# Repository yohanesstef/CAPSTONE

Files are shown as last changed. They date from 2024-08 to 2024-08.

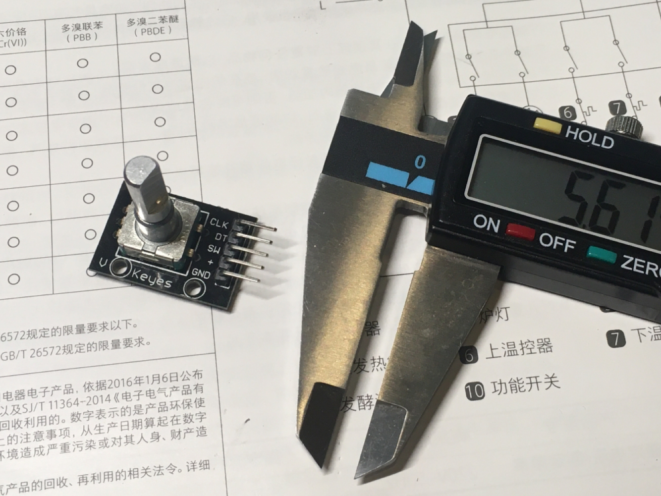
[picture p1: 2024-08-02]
full-bridge-inverter/ky-040-rotary-encoder-1.snapshot.1/Rotary Encoder - ODG/image/Measured by hand.png

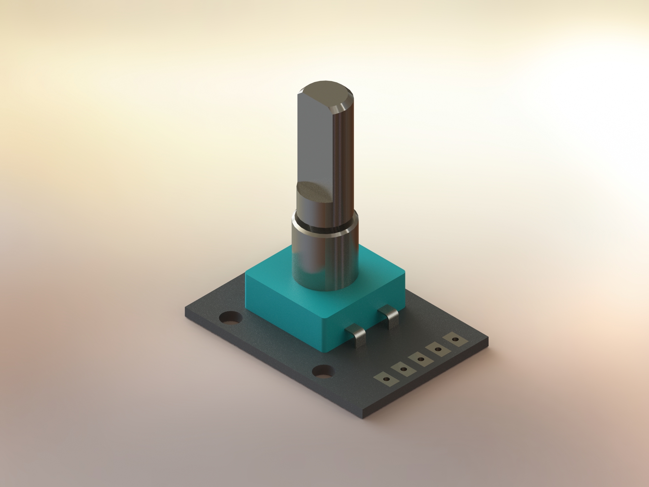
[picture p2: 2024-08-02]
full-bridge-inverter/rotary-encoder-ky-040-1.snapshot.3/Render Encoder 1.JPG

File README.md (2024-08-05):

# Wireless Power Transfer - CAPSTONE Project
WhatsApp Image 2024-08-05 at 20 47 46_10204884
This is repository for a Wireless Power Transfer. I have completed this project in semester 6 as an assignment for the CAPSTONE course. In this repository there are three PCB board that I design using KiCad 7.0. The boards are 12V Fullbridge Inverter, transmitter-board, and receiver-board. 
## Important notes !!!
This repository file management maybe kinda messy. But you can find 12V Fullbridge inside the directory:
```bash
.\full-bridge-inverter\full-bridge-inverter
```
That directory also includes Proteus simulation and source code for Arduino Nano.

Transmitter-board inside the directory:
```bash
.\transmitter-board
```
and receiver-board inside the directory:
```bash
.\receiver-board
```
## 1. 12V Fullbridge Inverter
This full-bridge inverter can convert 12VDC to 12VAC with a frequency ranging from 80kHz to 200kHz. This inverter is controlled by an Arduino Nano as the PWM generator. On the bottom left side of the board, you can adjust the frequency, and the value will be shown on the 0.91-inch OLED display.
### Simulation
Below is the simulation at maximum frequency (200kHz):


Below is the simulation at minimum frequency (80kHz):


### Schematic
Preview

### Layout


### Board Image

WhatsApp Image 2024-08-05 at 19 57 58_32873d33

### Specification
| Input Voltage | Output Voltage | Max Output Current | Operating Frequency |
| :---: | :---: | :---: | :---: |
| 5VDC - 15VDC | 7VAC - 15VAC | 3A | 80kHz - 200kHz* |

*operating frequency can be changed by program up to 1MHz
## 2. Transmitter Board
This transmitter board uses an LC series connection. This configuration helps reduce its impedance so the current flow can be maximized. The capacitor can be added or replaced with another one since the board uses an XT30 connector for the capacitor. The capacitor value needs to be calculated based on the resonant frequency to achieve maximum power transfer.



### Schematic


### Layout


### Board Image

WhatsApp Image 2024-08-05 at 19 57 39_28c1e7be
WhatsApp Image 2024-08-05 at 19 57 39_5e4d0d41

## 3. Receiver Board
This receiver board is similar to the transmitter board. The difference is that the receiver board uses an LC parallel connection to minimize its impedance and behave like a purely resistive circuit.
### Schematic


### Layout


### Board Image

WhatsApp Image 2024-08-05 at 20 37 52_3ca948d0
WhatsApp Image 2024-08-05 at 19 57 38_17e0c154

Do contact me if you have some question or want to colaborate with me.

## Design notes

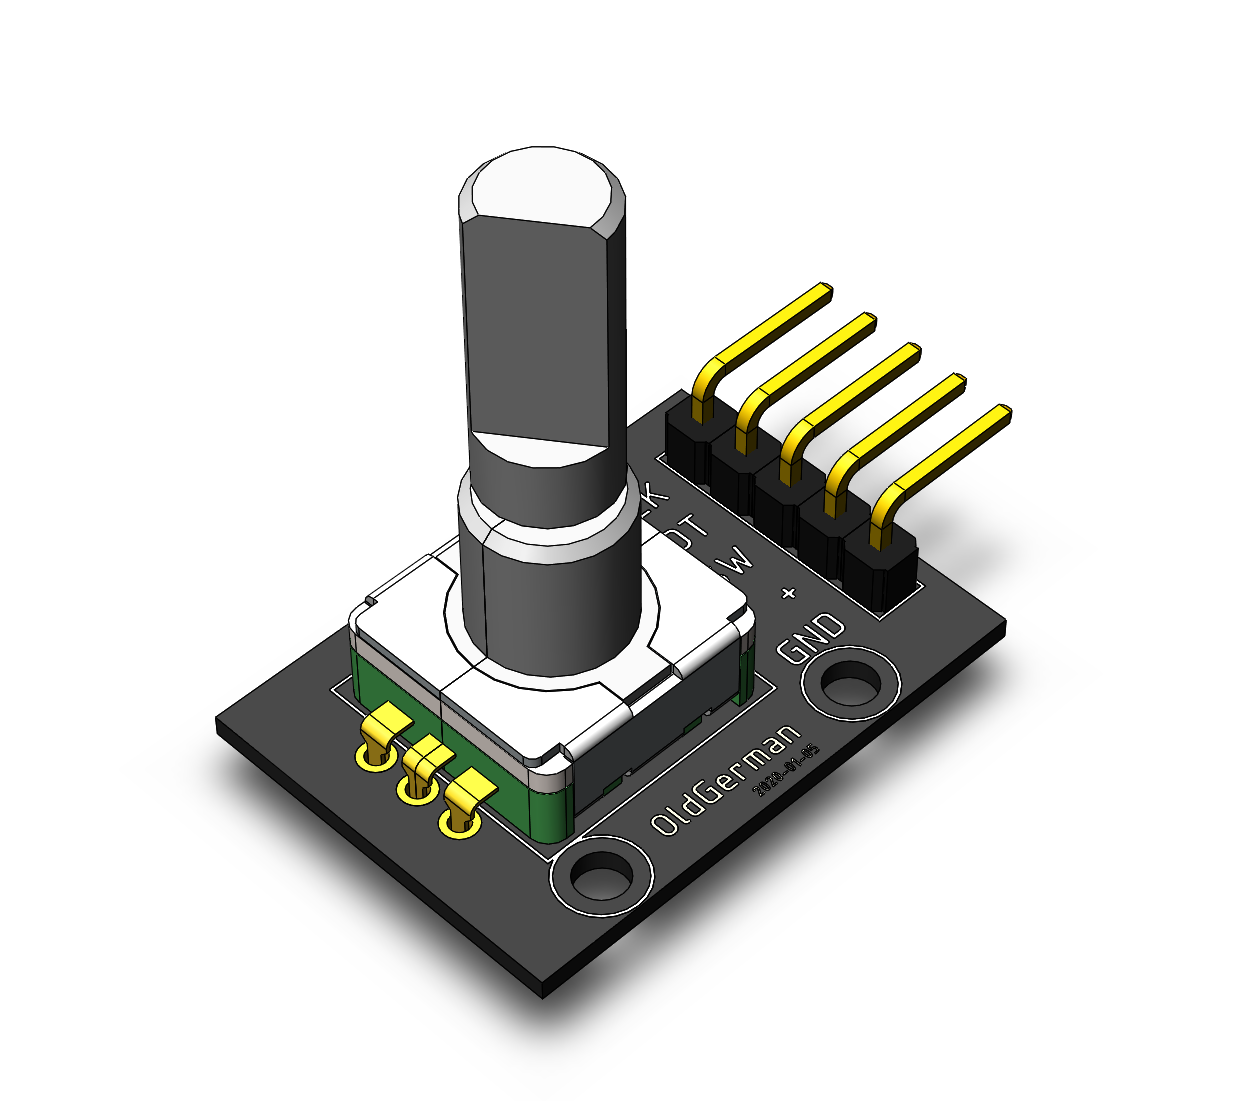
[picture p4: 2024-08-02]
full-bridge-inverter/ky-040-rotary-encoder-1.snapshot.1/Rotary Encoder - ODG/image/perspective 1 .png

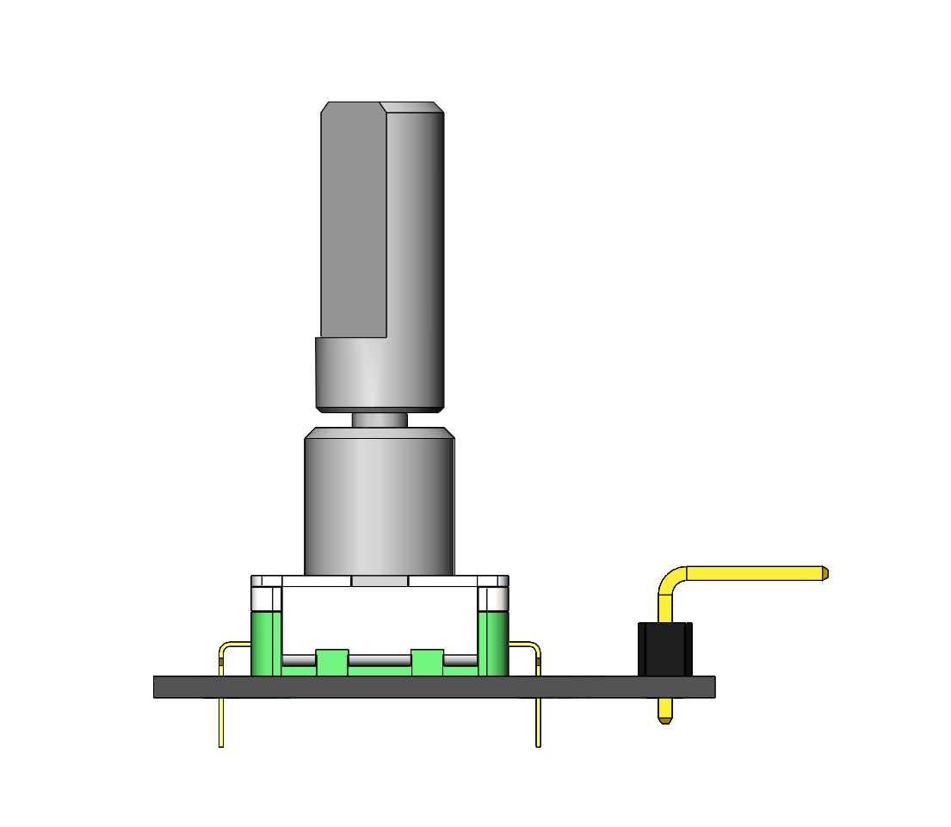
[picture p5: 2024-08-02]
full-bridge-inverter/ky-040-rotary-encoder-1.snapshot.1/Rotary Encoder - ODG/image/left.png

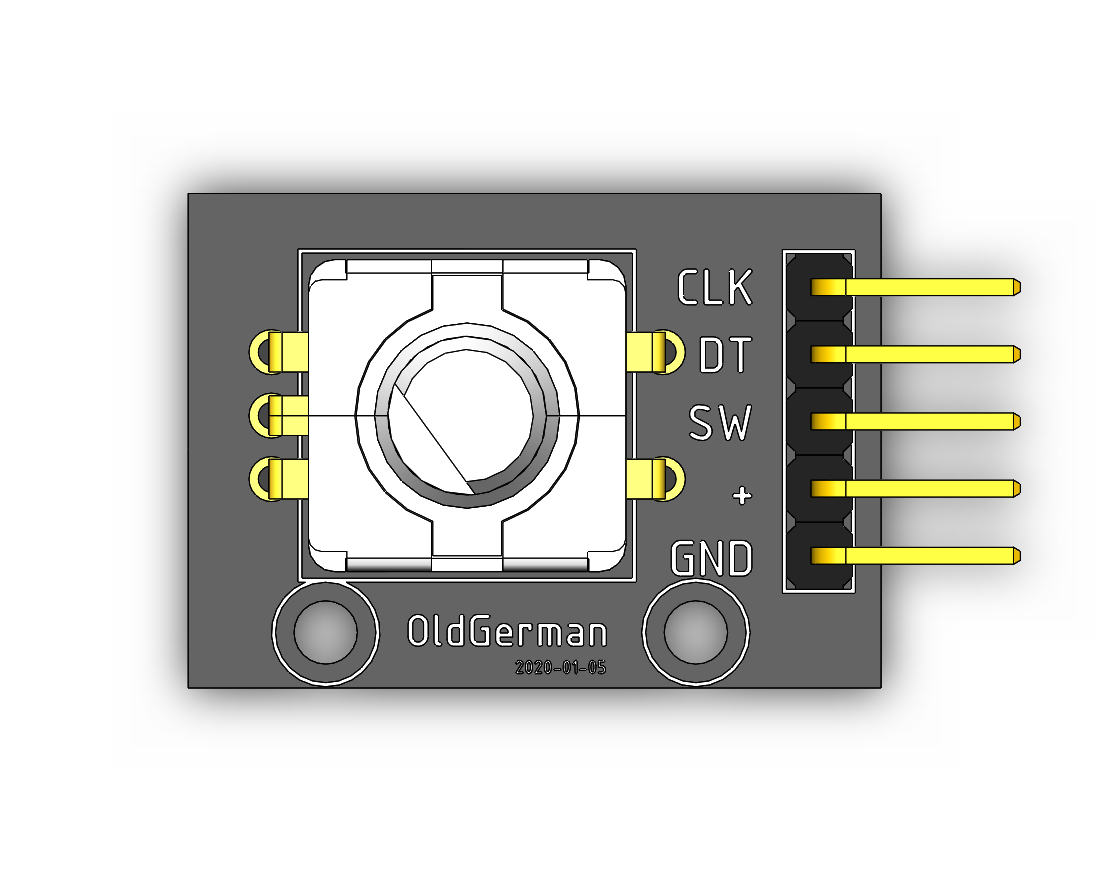
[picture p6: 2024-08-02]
full-bridge-inverter/ky-040-rotary-encoder-1.snapshot.1/Rotary Encoder - ODG/image/top.png

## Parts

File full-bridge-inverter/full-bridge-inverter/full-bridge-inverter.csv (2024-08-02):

Source: | C:\Users\ystef\Documents\KiCad\Project\CAPSTONE\full-bridge-inverter\full-bridge-inverter\full-bridge-inverter.kicad_sch
Date: | 18/06/2024 14:32:58
Tool: | Eeschema 7.0.10
Generator: | C:\Program Files\KiCad\7.0\bin\scripting\plugins/bom_csv_grouped_by_value_with_fp.py
Component Count: | 38
Ref | Qnty | Value | Cmp name | Footprint | Description | Vendor | DNP
A1 | 1 | Arduino_Nano_v3.x | Arduino_Nano_v3.x | Module:Arduino_Nano | Arduino Nano v3.x
C1, C7, C10 | 3 | 100u | C | Capacitor_THT:C_Radial_D8.0mm_H11.5mm_P3.50mm | Unpolarized capacitor
C2, C4, C5, C6, C11 | 5 | 10u | C | Capacitor_THT:C_Radial_D5.0mm_H11.0mm_P2.00mm | Unpolarized capacitor
C3 | 1 | 100n | C | Capacitor_THT:C_Disc_D4.3mm_W1.9mm_P5.00mm | Unpolarized capacitor
C8, C9 | 2 | 47n | C | Capacitor_THT:C_Disc_D4.3mm_W1.9mm_P5.00mm | Unpolarized capacitor
D1, D3 | 2 | 1N5820 | 1N5820 | Diode_THT:D_DO-201AD_P15.24mm_Horizontal | 20V 3A Schottky Barrier Rectifier Diode, DO-201AD
H1, H2, H3, H4 | 4 | MountingHole | MountingHole | MountingHole:MountingHole_3.2mm_M3_DIN965 | Mounting Hole without connection
J1, J2 | 2 | Screw_Terminal_01x02 | Screw_Terminal_01x02 | HB9500:HB9500 | Generic screw terminal, single row, 01x02, script generated (kicad-library-utils/schlib/autogen/connector/)
Q1, Q2, Q3, Q4 | 4 | IRLZ44N | IRLZ44N | Package_TO_SOT_THT:TO-220-3_Vertical | 47A Id, 55V Vds, 22mOhm Rds Single N-Channel HEXFET Power MOSFET, TO-220AB
R1, R2, R7, R8 | 4 | 10k | R | Resistor_THT:R_Axial_DIN0411_L9.9mm_D3.6mm_P12.70mm_Horizontal | Resistor
R3, R4, R5, R6 | 4 | 10 | R | Resistor_THT:R_Axial_DIN0411_L9.9mm_D3.6mm_P12.70mm_Horizontal | Resistor
U1 | 1 | LM7805_TO220 | LM7805_TO220 | Package_TO_SOT_THT:TO-220-3_Vertical | Positive 1A 35V Linear Regulator, Fixed Output 5V, TO-220
U2 | 1 | KY-040 | KY-040 | KY-040:KY-040-PORT
U3 | 1 | OLED-0.91 | OLED-0.91 | KiCad-SSD1306-0.91-OLED-4pin-128x32.pretty-master:SSD1306-0.91-OLED-4pin-128x32
U4, U5 | 2 | IR2110 | IR2110 | Package_DIP:DIP-14_W7.62mm_Socket_LongPads | High and Low Side Driver, 500V, 2.0/2.0A, PDIP-14
U6 | 1 | 74LS04 | 74LS04 | Package_DIP:DIP-14_W7.62mm_Socket_LongPads | Hex Inverter

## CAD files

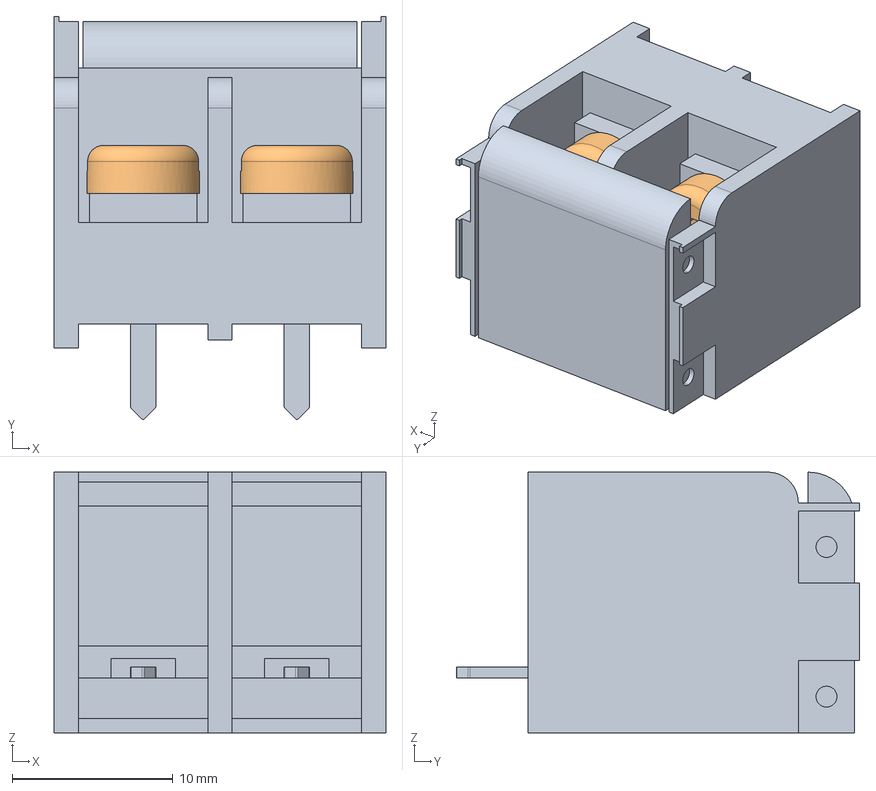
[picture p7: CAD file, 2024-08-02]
full-bridge-inverter/hb9500-barrier-teminal-block-1.snapshot.2/hb9500_asm.stp
20.6 x 25.0 x 16.2 mm
HB9500-1
M5X6 x 2

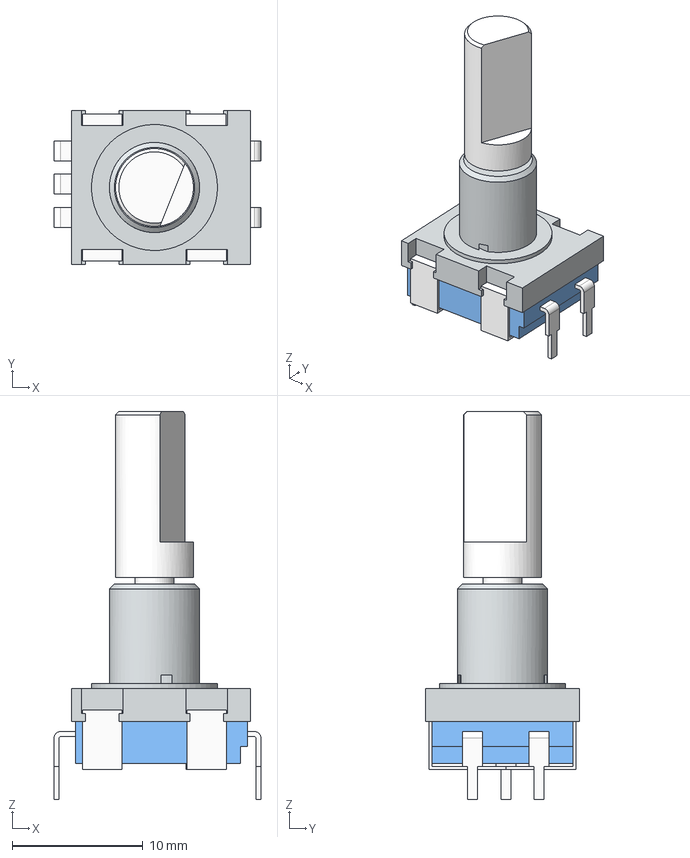
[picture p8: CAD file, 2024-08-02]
full-bridge-inverter/rotary encoder step files/Step Files/Rotary Encoder without pcb Assembly.stp
15.8 x 11.8 x 29.7 mm
mtg flange
body_encoder
pins_encoder body_2 x 5
shaft_encoder

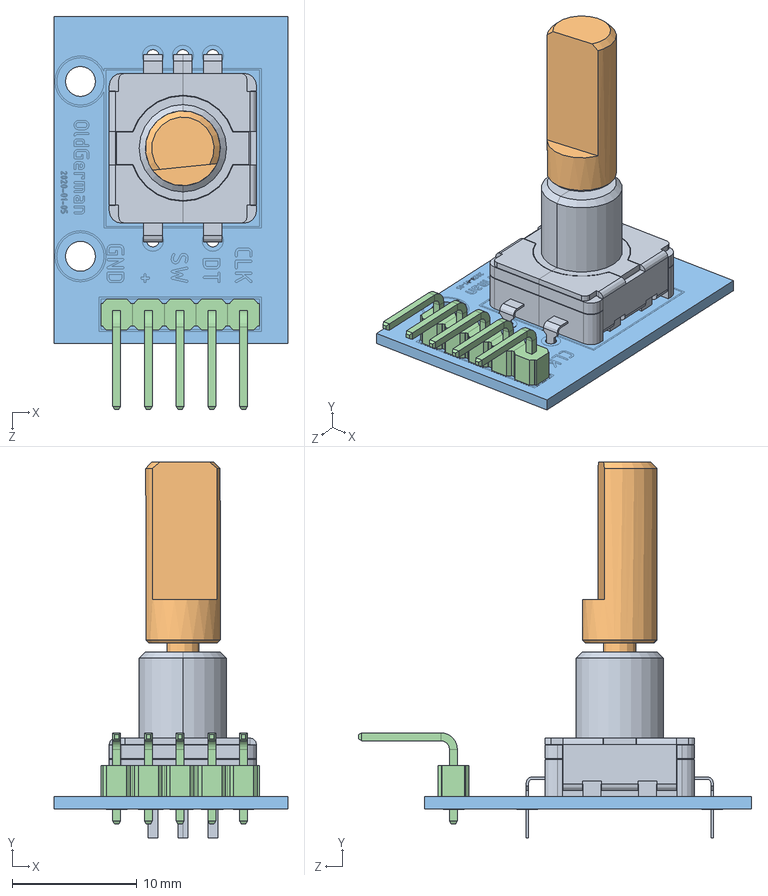
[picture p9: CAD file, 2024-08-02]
full-bridge-inverter/ky-040-rotary-encoder-1.snapshot.1/Rotary Encoder - ODG/sw2017 model/KY-040 Rotary Encoder.SLDASM
18.7 x 30.1 x 31.5 mm
Rotary Encoder
D-handle
pcb
2.54 5PIN 90

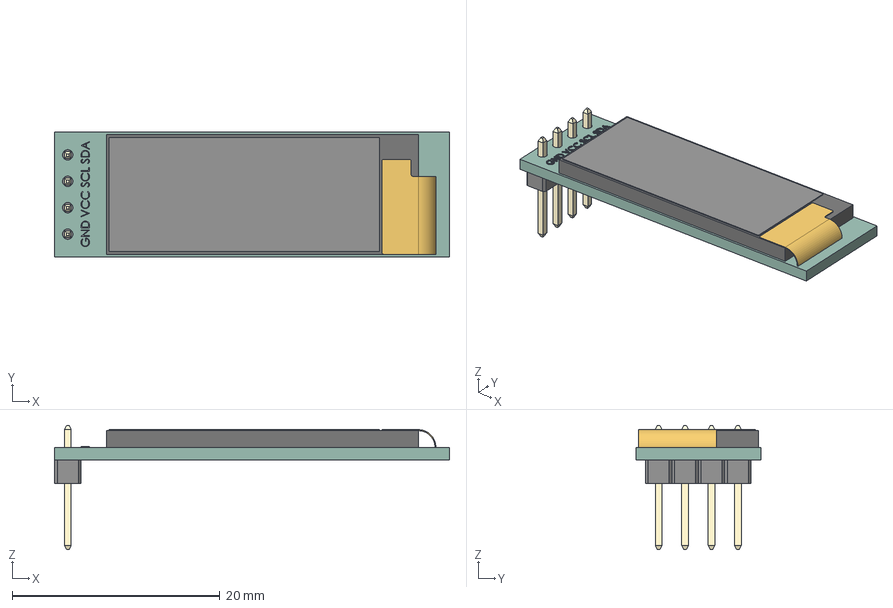
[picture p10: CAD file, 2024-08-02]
full-bridge-inverter/0-91-128x32-oled-display-1.snapshot.1/128x32-OLED.STEP
38.0 x 12.0 x 11.9 mm

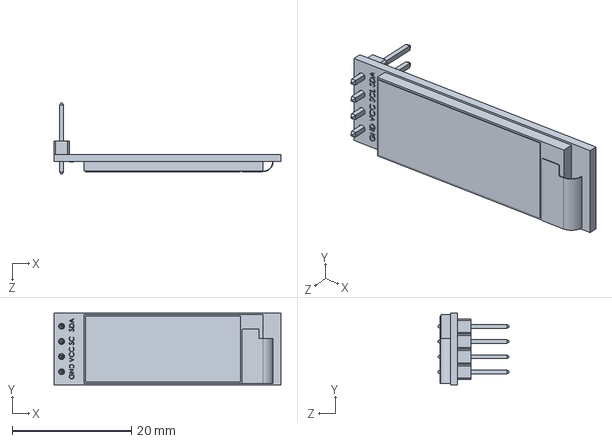
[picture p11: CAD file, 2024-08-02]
full-bridge-inverter/display-oled128x32-1.snapshot.4/128x32-OLED.STEP
38.0 x 12.0 x 11.9 mm

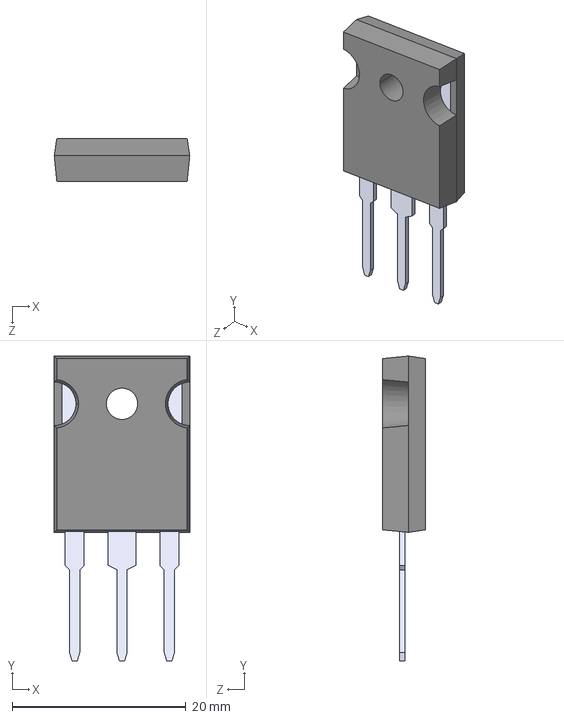
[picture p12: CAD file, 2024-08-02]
full-bridge-inverter/IRFP260N/IRFP260N.step
15.6 x 35.1 x 5.00 mm

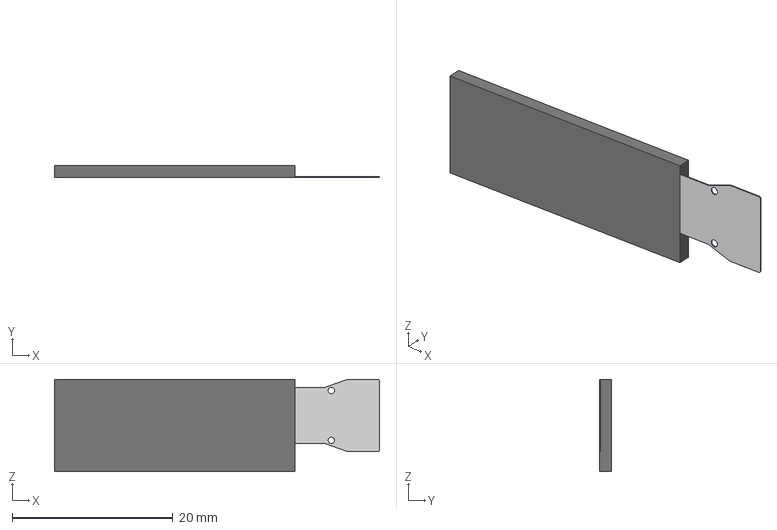
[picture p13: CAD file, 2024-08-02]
full-bridge-inverter/KiCad-SSD1306_OLED-0.91-128x32-master/SSD1306_OLED-0.91-128x32.step
40.5 x 1.45 x 11.5 mm

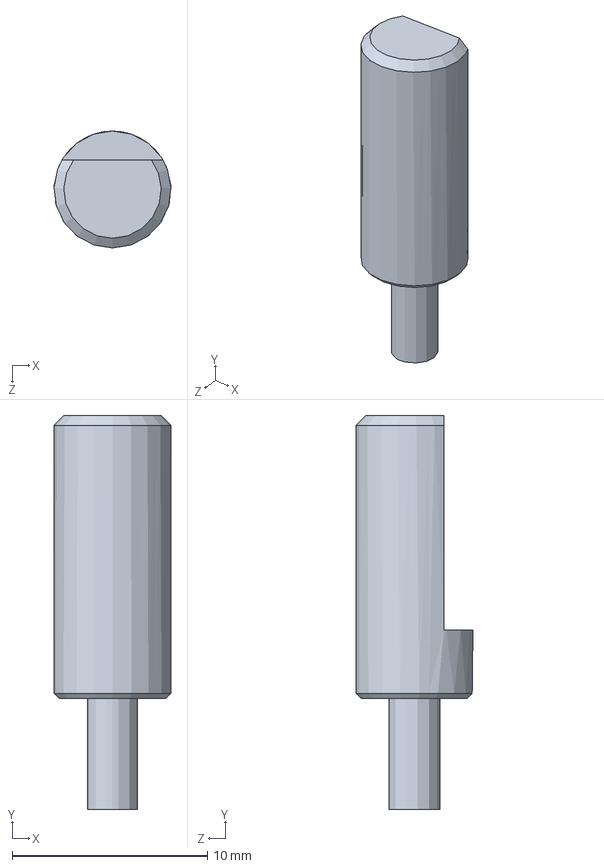
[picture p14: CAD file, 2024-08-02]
full-bridge-inverter/ky-040-rotary-encoder-1.snapshot.1/Rotary Encoder - ODG/sw2017 model/D-handle.SLDPRT
6.00 x 20.2 x 6.00 mm

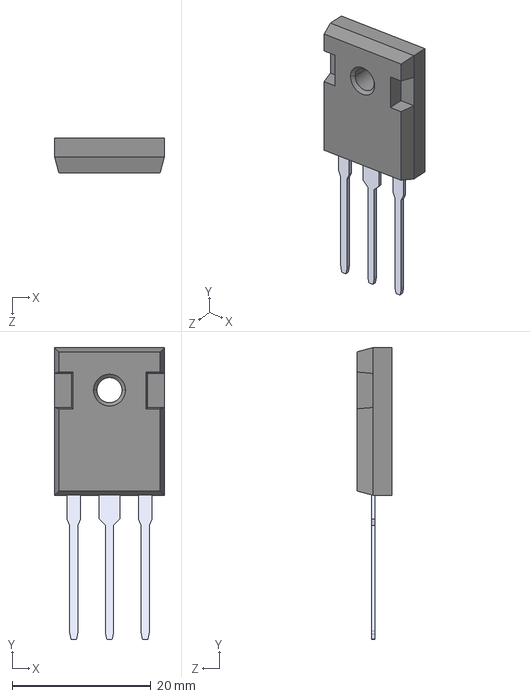
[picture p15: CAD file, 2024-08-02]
full-bridge-inverter/MUR3020WT/MUR3020WT.step
15.9 x 42.1 x 5.00 mm

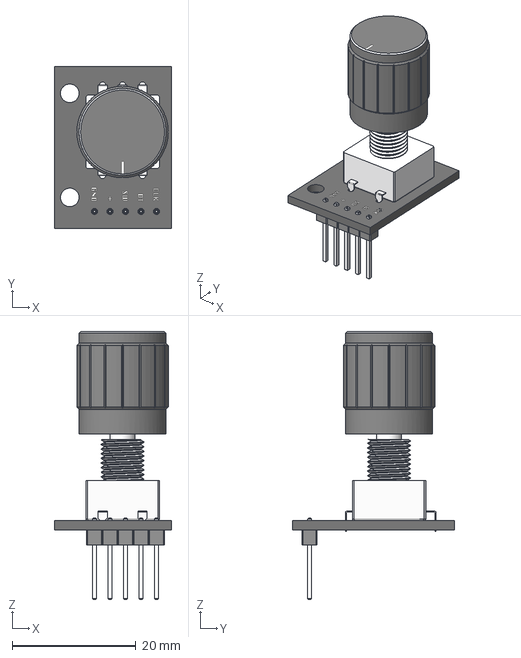
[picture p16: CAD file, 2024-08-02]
full-bridge-inverter/Rotary Encoder - KY-040.step
19.0 x 26.2 x 43.4 mm

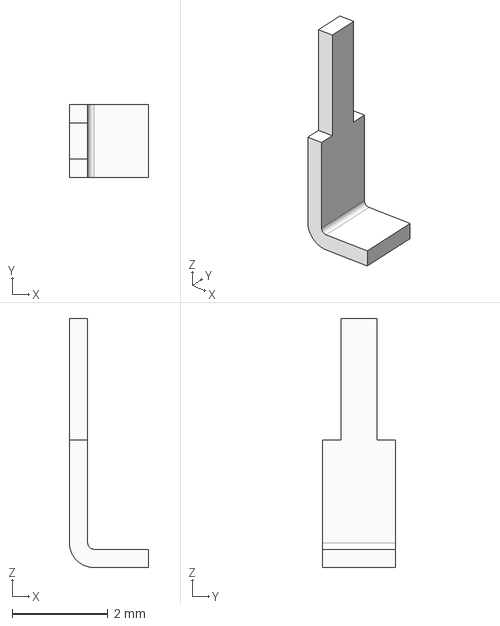
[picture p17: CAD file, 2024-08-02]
full-bridge-inverter/rotary encoder step files/Step Files/pins_encoder body_2.stp
1.65 x 1.52 x 5.21 mm

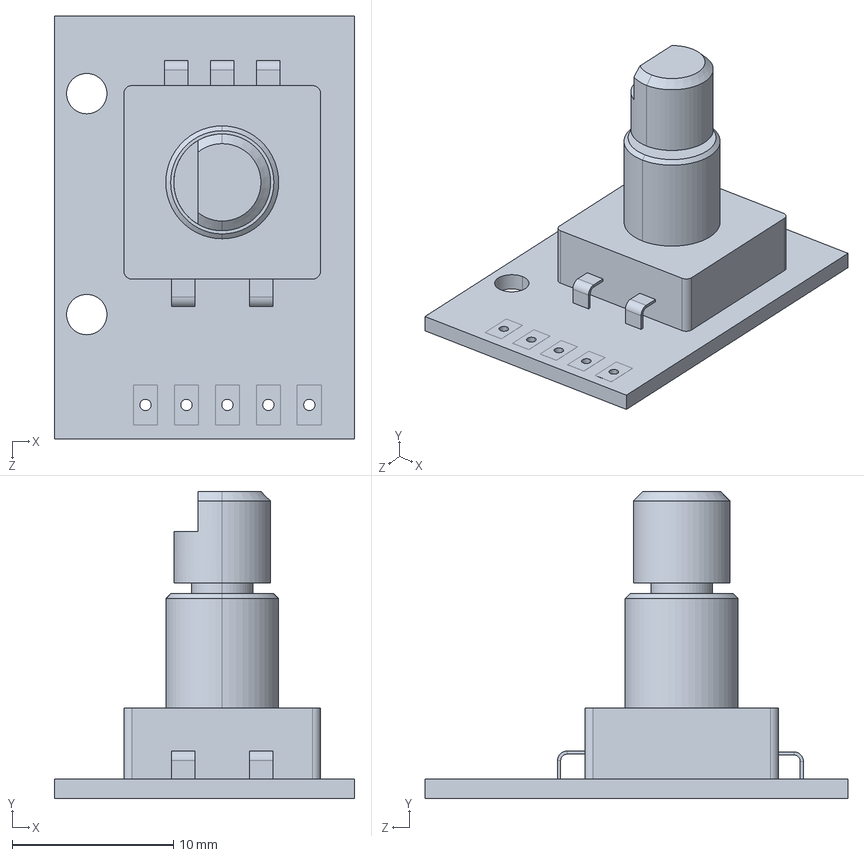
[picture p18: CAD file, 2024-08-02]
full-bridge-inverter/rotary-encoder-ky-040-1.snapshot.3/Encoder KY-040.STEP
18.6 x 19.1 x 26.2 mm

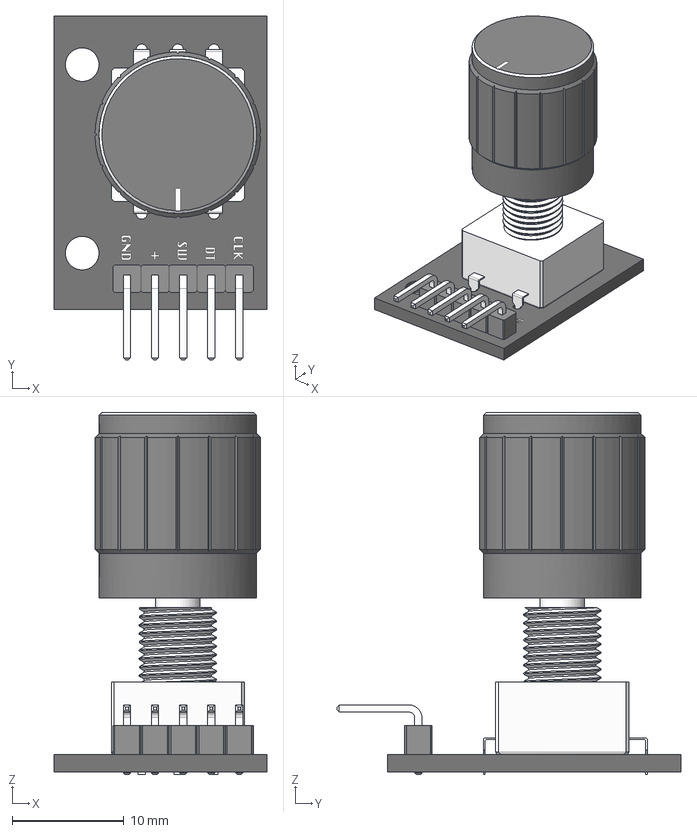
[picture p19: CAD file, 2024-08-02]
full-bridge-inverter/rotary-encoder-ky-040-2.snapshot.2/Rotary Encoder - KY-040.step
19.0 x 30.8 x 32.4 mm

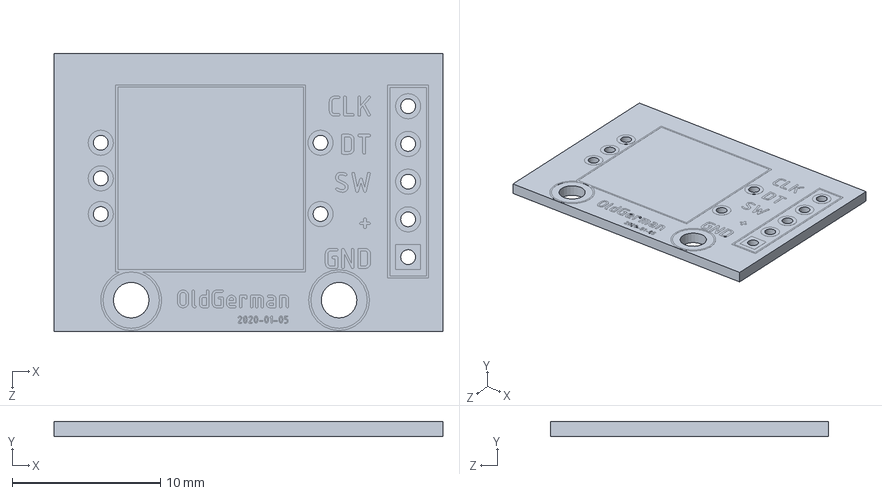
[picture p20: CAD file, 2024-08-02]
full-bridge-inverter/ky-040-rotary-encoder-1.snapshot.1/Rotary Encoder - ODG/sw2017 model/pcb.SLDPRT
26.2 x 1.02 x 18.7 mm

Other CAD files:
full-bridge-inverter/rotary encoder step files/Step Files/rotary encoder_chesr_2013.stp
full-bridge-inverter/ky-040-rotary-encoder-1.snapshot.1/Rotary Encoder - ODG/sw2017 model/Rotary Encoder.SLDPRT
full-bridge-inverter/rotary encoder step files/Step Files/90d pin_header.stp
full-bridge-inverter/ky-040-rotary-encoder-1.snapshot.1/Rotary Encoder - ODG/sw2017 model/2.54 5PIN 90.SLDPRT
full-bridge-inverter/Rotary Encoder/5 pin header.ipt
full-bridge-inverter/Rotary Encoder/90d pin_header.ipt
full-bridge-inverter/Rotary Encoder/OldVersions/mtg flange.0001.ipt
full-bridge-inverter/Rotary Encoder/OldVersions/pins_encoder body_2.0001.ipt
full-bridge-inverter/Rotary Encoder/OldVersions/pins_encoder body_2_2.0001.ipt
full-bridge-inverter/Rotary Encoder/OldVersions/rotary encoder_chesr_2013.0010.iam
full-bridge-inverter/Rotary Encoder/body_2.ipt
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

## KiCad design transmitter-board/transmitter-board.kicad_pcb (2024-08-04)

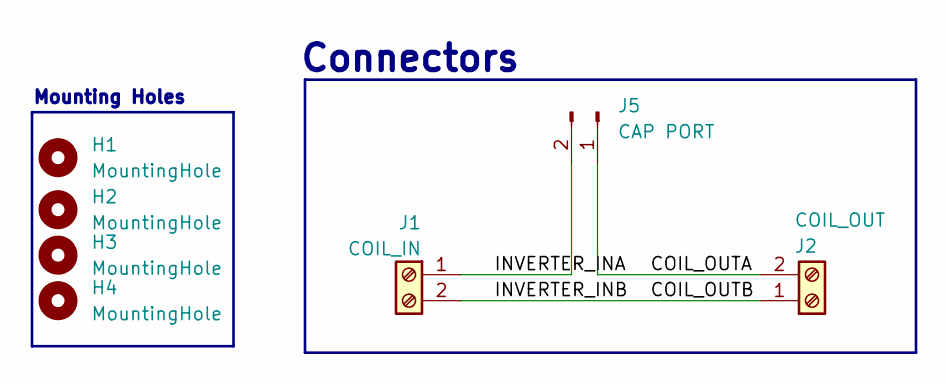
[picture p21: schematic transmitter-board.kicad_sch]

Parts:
H1, H2, H3, H4: MountingHole; MountingHole_3.2mm_M3
J1: COIL_IN; HB9500
J2: COIL_OUT; HB9500
J5: CAP PORT; AMASS_XT60-M_1x02_P7.20mm_Vertical

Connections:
/COIL_OUTA: J2.2, J5.1
/COIL_OUTB: J1.2, J2.1
/INVERTER_INA: J1.1, J5.2

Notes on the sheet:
Connectors
Mounting Holes

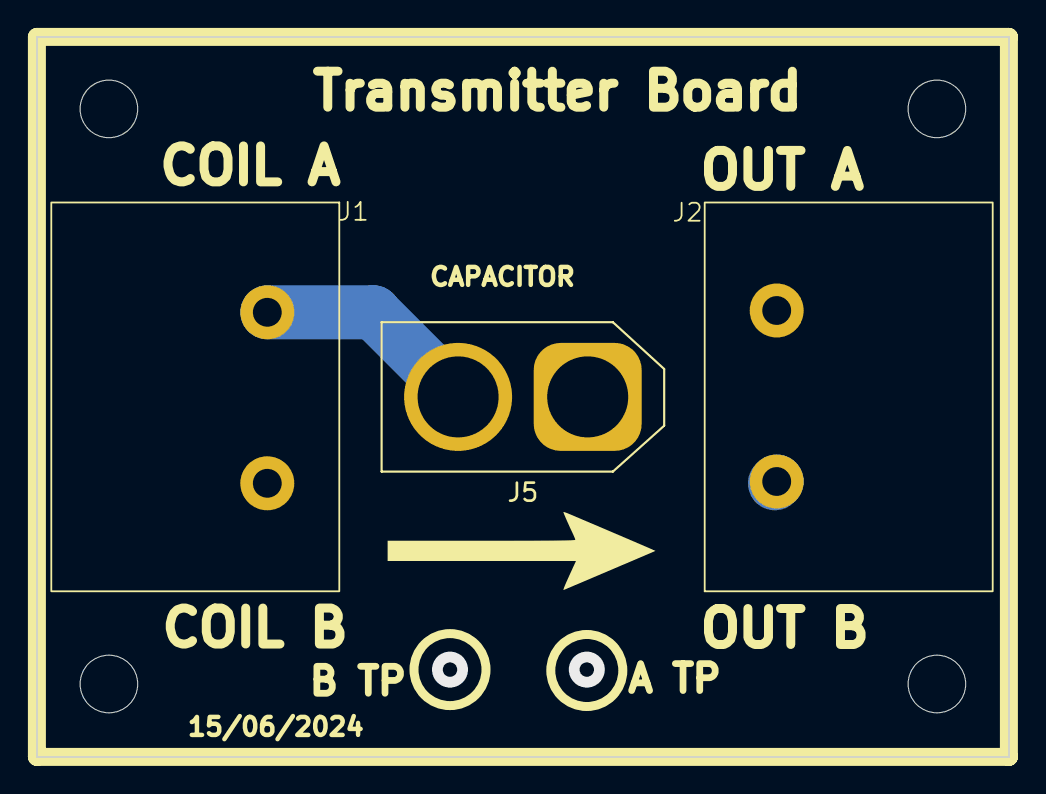
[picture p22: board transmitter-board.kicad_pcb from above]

Board: 2 copper layers, 54.0 x 40.0 mm, 7 parts (0 on the bottom side), 3 nets.

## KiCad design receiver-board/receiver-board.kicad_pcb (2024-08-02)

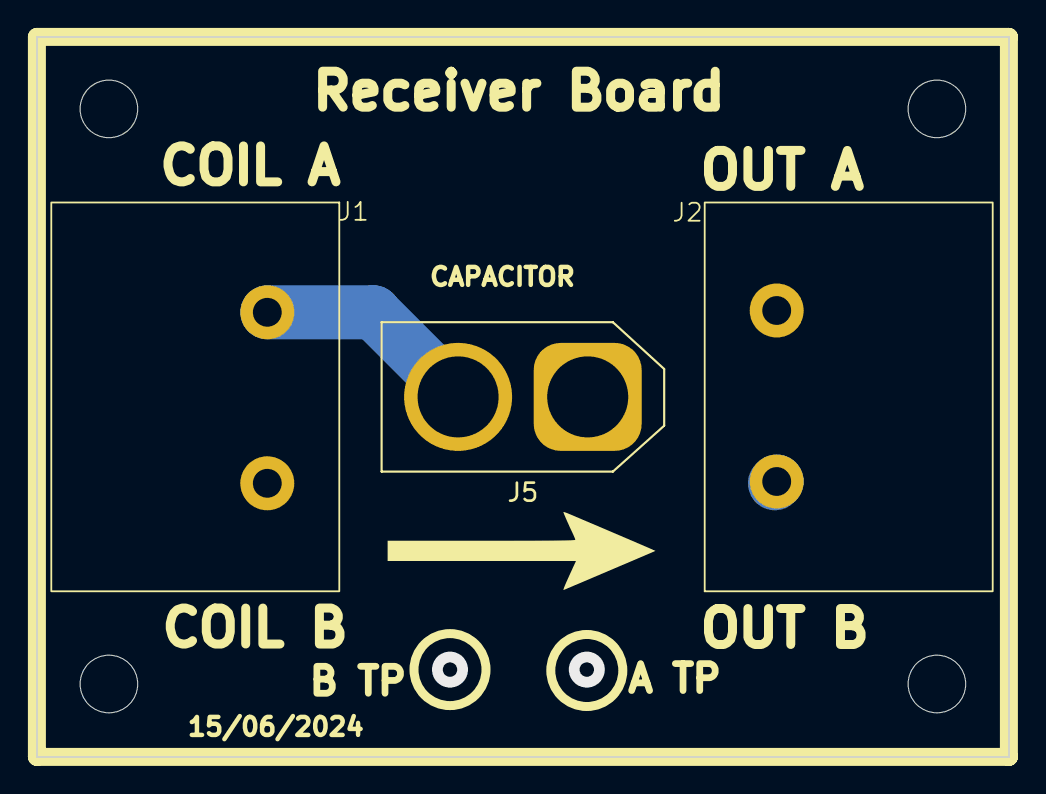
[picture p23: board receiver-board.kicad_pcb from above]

Board: 2 copper layers, 54.0 x 40.0 mm, 7 parts (0 on the bottom side), 2 nets.

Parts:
H1, H2, H3, H4: MountingHole; MountingHole_3.2mm_M3
J1, J2: Screw_Terminal_01x02; HB9500
J5: Conn_01x02_Pin; AMASS_XT60-M_1x02_P7.20mm_Vertical

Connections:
/COIL_OUTA: J1.1, J2.2, J5.2
/COIL_OUTB: J1.2, J2.1, J5.1

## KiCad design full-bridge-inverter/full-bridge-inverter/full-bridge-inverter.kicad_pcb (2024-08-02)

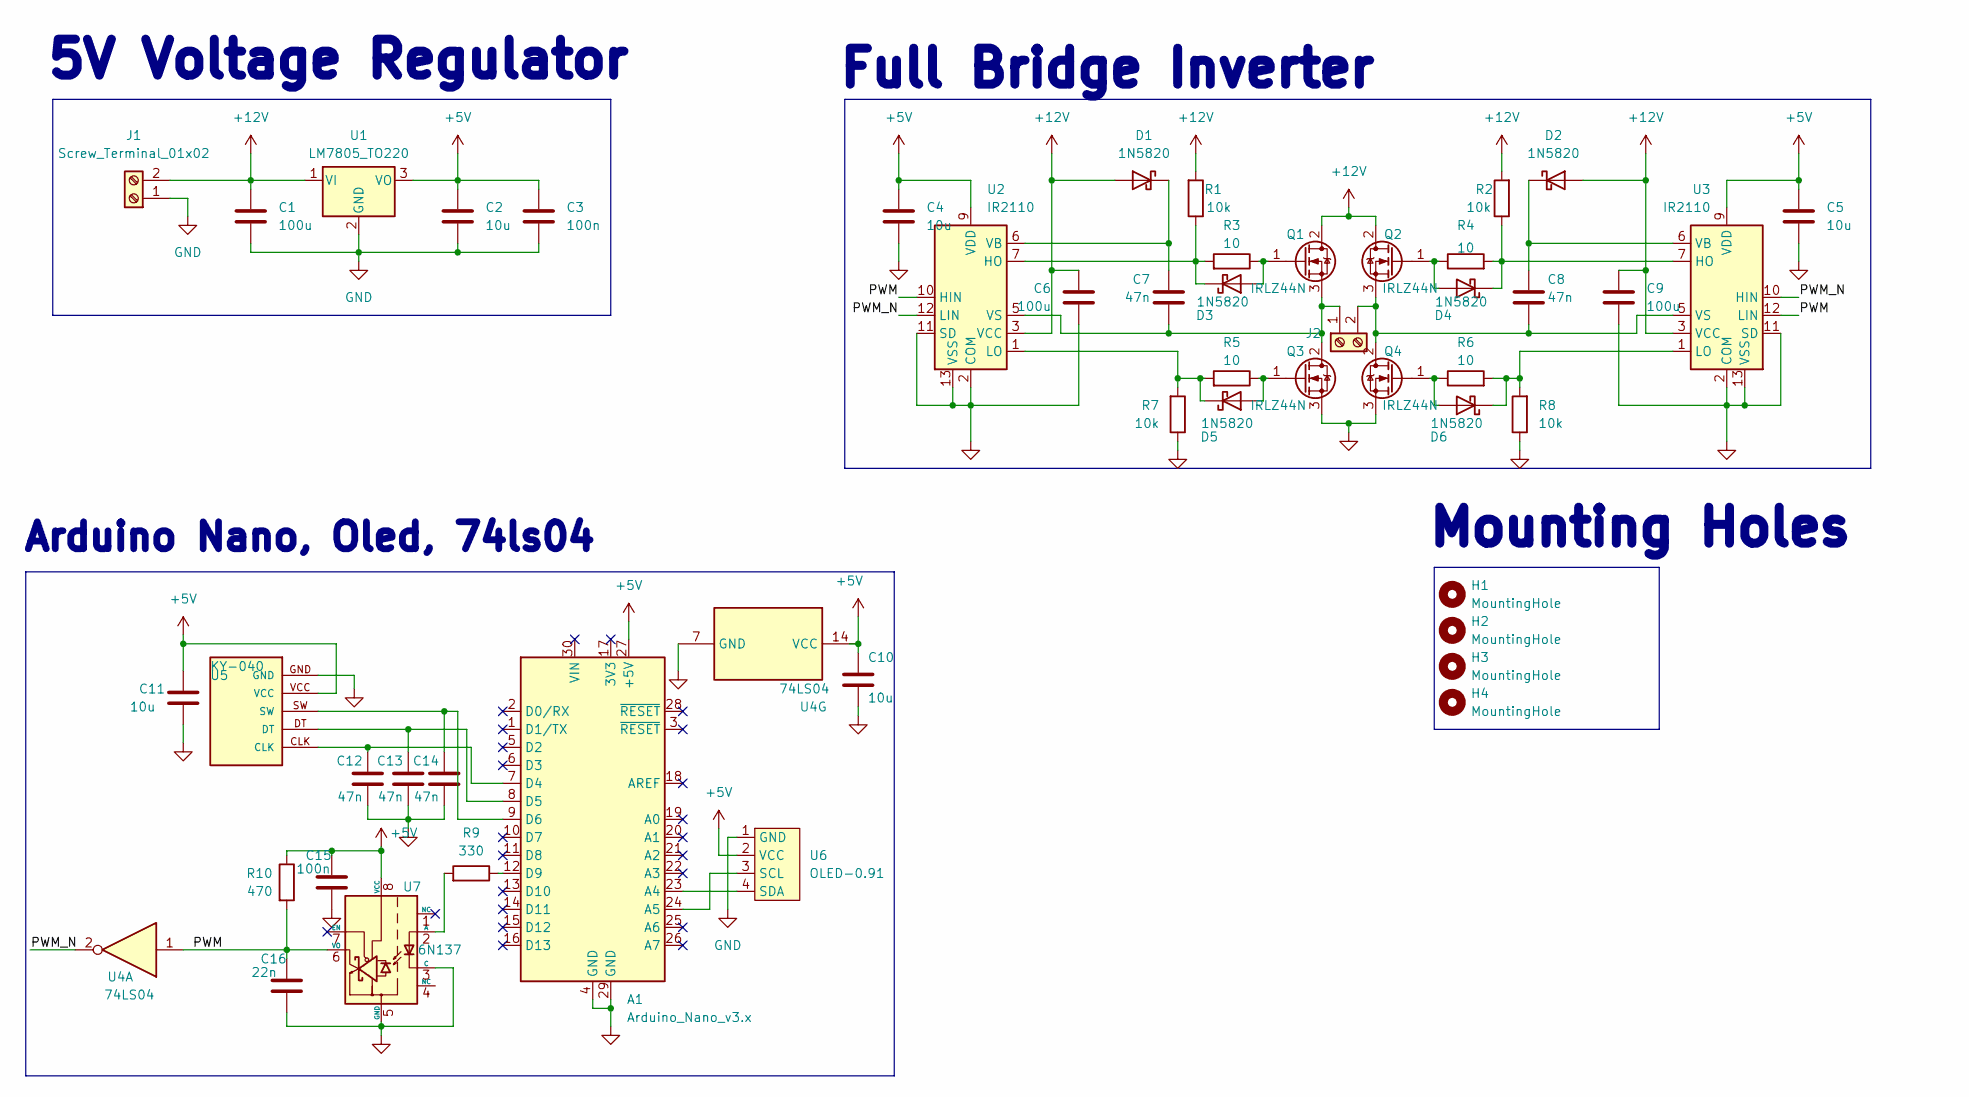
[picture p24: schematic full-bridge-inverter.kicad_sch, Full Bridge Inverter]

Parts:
A1: Arduino_Nano_v3.x; Arduino_Nano_v2
C1, C6, C9: 100u; C_Radial_D8.0mm_H11.5mm_P3.50mm
C2, C4, C5, C10, C11: 10u; C_Radial_D5.0mm_H11.0mm_P2.00mm
C3, C15: 100n; C_Disc_D4.3mm_W1.9mm_P5.00mm
C7, C8: 47n; C_Disc_D3.0mm_W1.6mm_P2.50mm
C12, C13, C14: 47n; C_Disc_D4.3mm_W1.9mm_P5.00mm
C16: 22n; C_Disc_D4.3mm_W1.9mm_P5.00mm
D1, D2, D3, D4, D5, D6: 1N5820; D_DO-201AD_P15.24mm_Horizontal
H1, H2, H3, H4: MountingHole; MountingHole_3.2mm_M3_DIN965
J1, J2: Screw_Terminal_01x02; HB9500
Q1, Q2, Q3, Q4: IRLZ44N; TO-220-3_Vertical
R1, R2, R7, R8: 10k; R_Axial_DIN0411_L9.9mm_D3.6mm_P12.70mm_Horizontal
R3, R4, R5, R6: 10; R_Axial_DIN0411_L9.9mm_D3.6mm_P12.70mm_Horizontal
R9: 330; R_0805_2012Metric
R10: 470; R_0805_2012Metric
U1: LM7805_TO220; TO-220-3_Vertical
U2, U3: IR2110; DIP-14_W7.62mm_Socket_LongPads
U4: 74LS04; DIP-14_W7.62mm_Socket_LongPads
U5: KY-040; KY-040-PORT
U6: OLED-0.91; SSD1306-0.91-OLED-4pin-128x32
U7: 6N137; DIP-8_W7.62mm

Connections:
+5V: A1.27 (+5V), C2.1, C3.1, C4.1, C5.1, C10.1, C11.1, C15.1, R10.1, U1.3 (VO), U2.9 (VDD), U3.9 (VDD), U4.14 (VCC), U5.VCC, U6.2 (VCC), U7.8 (VCC)
+12V: C1.1, C6.1, C9.1, D1.2 (A), D2.2 (A), J1.2, Q1.2 (D), Q2.2 (D), R1.2, R2.2, U1.1 (VI), U2.3 (VCC), U3.3 (VCC)
/PWM: C16.1, R10.2, U2.10 (HIN), U3.12 (LIN), U4.1, U7.6 (VO)
/PWM_N: U2.12 (LIN), U3.10 (HIN), U4.2
GND: A1.4 (GND), A1.29 (GND), C1.2, C2.2, C3.2, C4.2, C5.2, C6.2, C9.2, C10.2, C11.2, C12.2, C13.2, C14.2, C15.2, C16.2, J1.1, Q3.3 (S), Q4.3 (S), R7.1, R8.1, U1.2 (GND), U2.2 (COM), U2.11 (SD), U2.13 (VSS), U3.2 (COM), U3.11 (SD), U3.13 (VSS), U4.7 (GND), U5.GND, U6.1 (GND), U7.3 (C), U7.5 (GND)
unnamed: A1.23 (A4), U6.4 (SDA)
unnamed: A1.24 (A5), U6.3 (SCL)
unnamed: A1.7 (D4), C12.1, U5.CLK
unnamed: A1.8 (D5), C13.1, U5.DT
unnamed: A1.9 (D6), C14.1, U5.SW
unnamed: A1.12 (D9), R9.1
unnamed: C7.1, D1.1 (K), U2.6 (VB)
unnamed: C8.1, D2.1 (K), U3.6 (VB)
unnamed: D3.2 (A), Q1.1 (G), R3.1
unnamed: D3.1 (K), R1.1, R3.2, U2.7 (HO)
unnamed: D4.2 (A), Q2.1 (G), R4.1
unnamed: D4.1 (K), R2.1, R4.2, U3.7 (HO)
unnamed: D5.2 (A), Q3.1 (G), R5.1
unnamed: D5.1 (K), R5.2, R7.2, U2.1 (LO)
unnamed: D6.2 (A), Q4.1 (G), R6.1
unnamed: D6.1 (K), R6.2, R8.2, U3.1 (LO)
unnamed: C7.2, J2.1, Q1.3 (S), Q3.2 (D), U2.5 (VS)
unnamed: C8.2, J2.2, Q2.3 (S), Q4.2 (D), U3.5 (VS)
unnamed: R9.2, U7.2 (A)

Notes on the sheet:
Arduino Nano, Oled, 74ls04
Full Bridge Inverter
Mounting Holes
5V Voltage Regulator

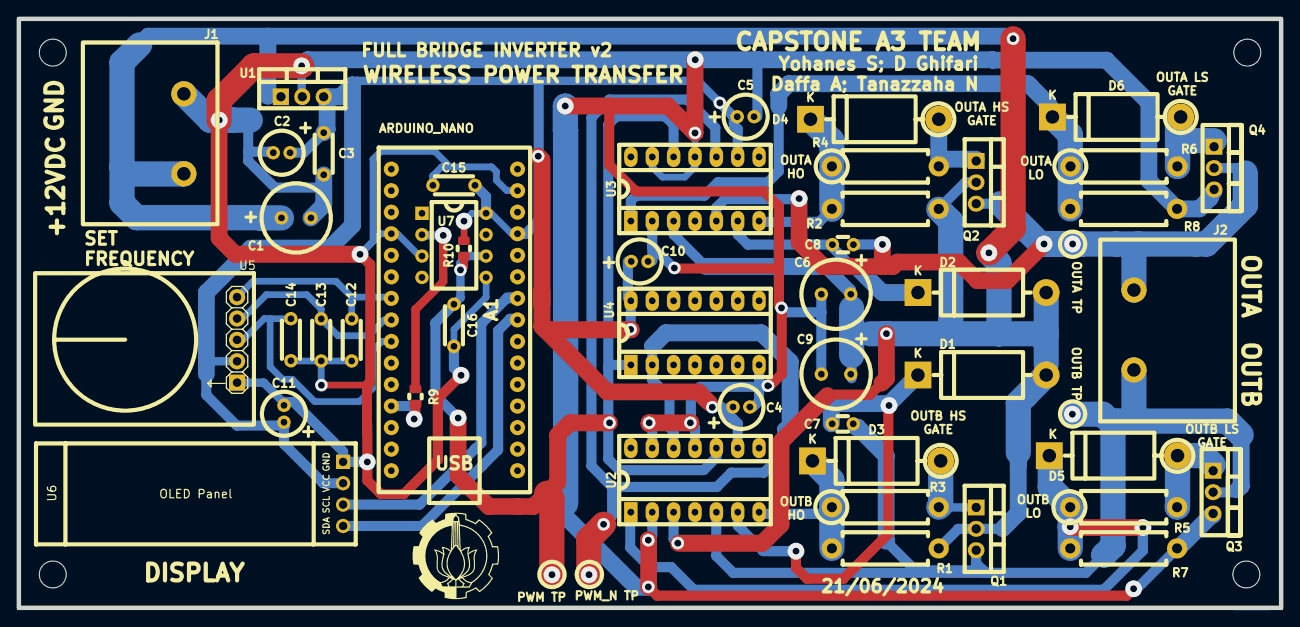
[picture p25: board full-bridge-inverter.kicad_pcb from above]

Board: 2 copper layers, 150.0 x 70.0 mm, 50 parts (0 on the bottom side), 24 nets.

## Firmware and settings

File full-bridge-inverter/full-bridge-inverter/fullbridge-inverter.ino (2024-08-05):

#include <U8g2lib.h>
#include <SPI.h>
#include <Wire.h>

U8G2_SSD1306_128X32_UNIVISION_F_HW_I2C oled(U8G2_R0);

#define CLK 4
#define DT  5
#define SW  6

struct{
  int a_prev, a_val;
  bool dir;
  int enc_count;
  unsigned long prev_tim;

  struct{
    bool now, prev;
    int count;
  }button;
}enc;

int analog;
int freq = 100;

void display_frequency(int num){
  char buf[20];
  oled.setFont(u8g2_font_ncenB12_tr);
  sprintf(buf,"f  : %d kHz",num);
  oled.clearBuffer();
  oled.drawStr(10, 20, buf);
  oled.sendBuffer();
}

void intro(){
  oled.clearBuffer();oled.drawStr(10, 15, "Capstone A3 Team");oled.sendBuffer();
  delay(1000);
  oled.clearBuffer();oled.drawStr(10, 15, "Capstone A3 Team.");oled.sendBuffer();
  delay(1000);
  oled.clearBuffer();oled.drawStr(10, 15, "Capstone A3 Team..");oled.sendBuffer();
  delay(1000);
  oled.clearBuffer();oled.drawStr(10, 15, "Capstone A3 Team...");oled.sendBuffer();
  delay(1000);
  oled.clearBuffer();oled.drawStr(15, 15, "Yohanes Dakita");oled.drawStr(30, 25, "Daffa Acha");oled.sendBuffer();
  delay(2000);
  oled.clearBuffer();oled.drawStr(10, 15, "Inverter Board from");oled.sendBuffer();
  delay(2000);
  oled.clearBuffer();oled.drawStr(15, 10, "Wireless Power");oled.drawStr(35, 20, "Transfer");oled.sendBuffer();
  delay(2000);
}

void setup() {
  //------------------OLED
  oled.begin();
  oled.setFlipMode(1);
  oled.clearBuffer();
  oled.setFont(u8g2_font_ncenB08_tr);

  // -----------------ENCODER
  pinMode(CLK,INPUT);
  pinMode(DT, INPUT);
  pinMode(SW, INPUT_PULLUP);
  enc.a_prev = digitalRead(CLK);
  enc.button.prev = digitalRead(SW);


  Serial.begin(9600);
  pinMode(9,1);
  pinMode(13,1);
  pinMode(A0,0);
  TCCR1A = 0;
  TCCR1B = 0;
  TCCR1A |= (1 <<WGM11) | (1 << COM1A1) | (1 << COM1B1);
  TCCR1B |= (1 << CS10) | (1 << WGM12) | (1 << WGM13);

  intro();
  // put your setup code here, to run once:

}

void loop() {
    enc.button.now = digitalRead(SW);
    if(enc.button.now != enc.button.prev) {
      enc.button.count++;
      Serial.print("Button: ");Serial.println(enc.button.count);
    }
    enc.button.prev = enc.button.now;     
    enc.a_val = digitalRead(CLK);
    if (enc.a_val != enc.a_prev){
      if(digitalRead(DT) != enc.a_val){
        enc.enc_count++;
        freq ++;
        if(freq>=200)freq = 200;
        enc.dir = true;
      }
      else if(digitalRead(DT) == enc.a_val){
        enc.enc_count--;
        freq--;
        if(freq<=80)freq = 80;
        enc.dir = false;
      }
      Serial.print("dir: ");Serial.println((enc.dir) ? "clock wise" : "counter clock wise");
      Serial.print("Count: ");Serial.println(enc.enc_count);
      enc.prev_tim = millis();
    }
    enc.a_prev = enc.a_val;
    // display_frequency(200 - freq + 80);

  // ICR1 = map(analogRead(A0),10,1023,80,200);
  // ICR1 = freq;
  OCR1A = ICR1 / 2;
  float hertz = 1 / ((float)ICR1/16000);
  // display_frequency(200 - ICR1 + 80);
  display_frequency(hertz);
}

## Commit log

2024-08-04 add receiver board
    [receiver-board.kicad_pcb, receiver-board.kicad_sch, transmitter-board.kicad_pcb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]
2024-08-05 add source code
    [full-bridge-inverter.kicad_sch]
